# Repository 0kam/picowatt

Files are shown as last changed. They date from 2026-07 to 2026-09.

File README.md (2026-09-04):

# picowatt

Raspberry Pi Pico 2 + INA228 による PPK2 ライクな消費電力測定システム。

## クイックスタート

### リリース版を使う(推奨)

1. **ファームウェア**: [Releases](https://github.com/0kam/picowatt/releases) から
   `picowatt-vX.Y.Z.uf2` をダウンロードし、BOOTSEL ボタンを押しながら Pico 2 を
   USB 接続して現れる `RP2350` ドライブにドラッグ(または
   `picotool load -fx picowatt-vX.Y.Z.uf2`)。
2. **PC アプリ**: [uv](https://docs.astral.sh/uv/) があれば1行で起動できる:

   ```sh
   uvx picowatt        # GUI
   uvx --from picowatt picowatt-cli --seconds 10 --csv out.csv
   ```

   (pip 派は `pipx install picowatt` でも可)

### ソースからのビルドと書き込み

必要なもの: cmake、ARM GNU toolchain、[pico-sdk](https://github.com/raspberrypi/pico-sdk) 2.3+(`lib/tinyusb` サブモジュール込み)、picotool 2.3+。

```sh
export PICO_SDK_PATH=~/pico-sdk            # 既定値
export PICO_TOOLCHAIN_PATH=~/toolchains/arm-gnu-toolchain-...  # PATH に無い場合
./firmware/build.sh                        # → firmware/build/picowatt.uf2

# 初回のみ BOOTSEL ボタンを押しながら USB 接続して:
picotool load -fx firmware/build/picowatt.uf2
# 2回目以降はボタン不要(実行中ファームがリブートコマンドを受け付ける)
```

UF2 ドライブへのドラッグ&ドロップでも書き込めるが、USB マスストレージが
制限された環境では picotool 経由(PICOBOOT)が使える。

### PC アプリ

```sh
cd app
uv sync
uv run picowatt        # GUI
uv run picowatt-cli --seconds 10 --csv out.csv   # ヘッドレスキャプチャ
```

GUI: Connect → Start でストリーミング開始。Measure チェックで電力プロット上の
任意区間を選択して Wh/Ah を積算。Log CSV… で全サンプルをファイルに記録。
Calibrate… でゼロ校正・1点ゲイン校正(ボードIDごとに自動保存され、接続時に
自動適用)。プロトコル仕様は [docs/protocol.md](docs/protocol.md)、実測性能は
[docs/verification.md](docs/verification.md) を参照。値がおかしいときは
[docs/troubleshooting.md](docs/troubleshooting.md)（症状から引ける）。

## 概要

INA228 電力モニタを Pico 2 で読み取り、USB シリアル経由で PC に転送。PC 側アプリでリアルタイム表示・ロギング・任意区間の電力量(Wh)積算を行う。

対応する測定モード:

- **消費電力測定** — 機器の消費電力を INA228 1枚で測定
- **DC-DC 効率測定** — INA228 2枚で入出力を同時測定し、効率を算出

## ハードウェア構成

| 役割 | 型番 | 備考 |
|---|---|---|
| MCU | Raspberry Pi Pico 2 (RP2350) | USB CDC で PC 接続 |
| 電力モニタ | Adafruit INA228 ×2 | 15mΩ 0.1% シャント搭載、20bit ADC |
| ディスプレイ | SSD1306 128×64 I2C OLED | 秋月 |
| 電源 | アズワン PS30V5A10 | 0-30V / 0-5A |
| 電子負荷 | ET5410A+ | 効率測定時の負荷掃引用 |

### I2C アドレス

| デバイス | アドレス | 設定 |
|---|---|---|
| SSD1306 OLED | `0x3C` | — |
| INA228 #1 (入力側) | `0x40` | デフォルト |
| INA228 #2 (出力側) | `0x41` | 基板裏 A0 ジャンパを閉 |

### 結線

ロジック側は I2C0 バスに全デバイスをぶら下げる。ブレッドボード配線の代わりに
キャリア基板を起こす場合は [hardware/](hardware/README.md) を参照(KiCad プロジェクト)。

| Pico 2 | 接続先 |
|---|---|
| 3V3 OUT (pin 36) | INA228 ×2 VIN / OLED VCC |
| GND (pin 38) | INA228 ×2 GND / OLED GND / 電源 − (1点のみ) |
| GP4 (pin 6) SDA | INA228 ×2 SDA / OLED SDA |
| GP5 (pin 7) SCL | INA228 ×2 SCL / OLED SCL |

I2C プルアップは INA228 基板の 10kΩ が効くため追加不要。

ブレッドボードで組む場合の全体図（ロジック配線 + 電源経路）:

ブレッドボード配線: 消費電力測定

ブレッドボード配線: DC-DC 効率測定

電力ラインはハイサイド測定。**基板裏の VBus ジャンパを閉じる**(VBUS が VIN+ に接続され、ハイサイド構成になる)。

```
電源(+) → #1 VIN+ ─[15mΩ]─ #1 VIN− → DUT(+)
電源(−) ←──────────────────────────── DUT(−)
```

キャリア基板でのつなぎ方（赤 = ＋側、青 = −側。USB が左、端子台が上辺）:

消費電力測定のつなぎ方

効率測定時は出力側に #2 を追加:

```
DUT出力(+) → #2 VIN+ ─[15mΩ]─ #2 VIN− → 電子負荷(+)
DUT出力(−) ←───────────────────────────── 電子負荷(−)
```

DC-DC 効率測定のつなぎ方

ch1 用の INA228 は裏の A0 ジャンパを閉じて右の J3 に挿す。詳細は
[hardware/README.md](hardware/README.md#使い方配線図)。

**電源の − は必ず picowatt の GND（キャリア基板なら J5）に繋ぐ。** INA228 は
バス電圧を自分の GND ピン基準で測るので、この 1 本が無いと基板が電源系から
浮き、VBUS が 0 V と −数十 V の間を 50/60 Hz で振動する（実在しない電圧）。
GUI はステータスバー右端に赤字の警告を出し、`picowatt-cli` は
`WARNING: bus voltage goes negative` を出す。図解は [docs/troubleshooting.md](docs/troubleshooting.md)。

GND リンクを忘れるとこうなる

GND の共通接続は 1 点のみ。複数箇所で接続するとループになる。

## キャリブレーション

INA228 は `SHUNT_CAL` レジスタ (0x02) にシャント値とフルスケールから決まる係数を書き込む必要がある。

```
CURRENT_LSB = 最大期待電流 / 2^19
SHUNT_CAL   = 13107.2e6 × CURRENT_LSB × R_SHUNT
```

`R_SHUNT = 0.015` (Adafruit ボード搭載値)。

デフォルト設定 (3A 想定, ADCRANGE=0 / ±163.84mV):

```
CURRENT_LSB = 8e-6        # 8 µA/LSB, フルスケール約 4.19A
SHUNT_CAL   = 1573
```

低電流モード (ADCRANGE=1 / ±40.96mV) では CURRENT_LSB を 1/4 に下げて分解能を上げる。
ADCRANGE=1 では **SHUNT_CAL の計算値を 4 倍**する必要があるが、LSB の 1/4 と相殺して
レジスタ値は同じになる:

```
CURRENT_LSB = 2e-6        # 2 µA/LSB, フルスケール約 1.05A
SHUNT_CAL   = 1573        # = 4 × 13107.2e6 × 2e-6 × 0.015
```

出荷時のシャント実値は公称から数%ずれることがあるため、既知電流での 1 点校正を推奨。

## 機能要件

### ファームウェア (Pico 2)

- INA228 ×2 の初期化・設定変更 (ADCRANGE, 変換時間, 平均化回数)
- 定期サンプリングと USB シリアルへのストリーミング
- OLED へのリアルタイム数値表示
- PC からのコマンド受信 (レンジ切替、サンプリングレート変更、ゼロ校正、モード切替)
- I2C は 400kHz 以上 (Pico 2 は 1MHz まで可)

### PC アプリ

- シリアル接続とリアルタイムグラフ表示 (電圧 / 電流 / 電力)
- CSV ロギング
- **表示中の任意範囲を選択して電力量(Wh)を積算**
- 効率モード時は入出力電力と効率(%)を同時表示
- 測定設定の変更 UI

## 想定サンプリングレート

I2C 経由のため PPK2 (100kSa/s) 相当は狙わない。数百 Hz〜数 kHz を目標。変換時間と平均化回数の設定でノイズと速度をトレードオフする。

## 参考

- [Adafruit INA228 Learn Guide](https://learn.adafruit.com/adafruit-ina228-i2c-power-monitor)
- INA228 データシート (TI)

## ライセンス

GPL-3.0 — 詳細は [LICENSE](LICENSE) を参照。

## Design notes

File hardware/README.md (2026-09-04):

# picowatt キャリア基板

Pico 2 + INA228 ×2 + SSD1306 OLED を 1 枚に載せるキャリア基板。ロジックはすべて
I2C0 にぶら下がるだけなので、この基板は **電源と I2C を配るだけ** で能動素子を持たない。

- 基板サイズ **92 × 70 mm**（2 層、厚さ 1.6mm）。100×100mm 以内なので各社の最安枠に収まる
- 子基板（Pico 2 / INA228 ×2 / OLED）はすべて 2.54mm ソケットで着脱可能
- 高さはすべて **11.0mm の同一面** に揃う（ソケットのハウジング高さ 8.5mm +
  ピンヘッダのハウジング厚み 2.5mm、いずれも秋月の仕様値）

KiCad 10 で `picowatt-carrier.kicad_pro` を開く。シンボルとフットプリントのうち
本基板固有のものは `picowatt.kicad_sym` / `picowatt.pretty/` にプロジェクト内蔵。
残りは KiCad 標準ライブラリを参照する。

> KiCad を一度も起動していない環境ではグローバルライブラリテーブルが未作成のため、
> 標準ライブラリ参照がエラーになる。KiCad を一度起動すれば自動生成される。

## 配置の考え方

配線の向きを 3 方向に分離してある。

| 方向 | 出ていくもの |
|---|---|
| 上辺（奥） | INA228 ×2 のネジ端子台、GND 端子台 — 太い電源線はすべて奥へ |
| 左辺 | Pico 2 の Micro-USB B — PC へ |
| 手前 | OLED の表示面 |

INA228 の端子台が基板の外を向くので、電源線は基板の上を這わない。

J5 (GND 端子台) も同じ向きに揃えるため **180° 回転して配置してある。** TB007-508 の
機械図面 (SECTION A-A) では、ピン列は電線挿入面ではなく**背面から 4.90mm**（挿入面からは
5.35mm）の位置にある。回転 0 のままだと電線が手前から入り、基板の上をまたぐことになる。

## 回路

ネットは 6 本だけ。

| ネット | 接続先 |
|---|---|
| `+3V3` | Pico 2 pin36 (3V3 OUT) → INA228 ×2 の VIN、OLED VDD、プルアップ、パスコン |
| `GND` | Pico 2 の GND 群、各子基板 GND、GND 端子台、TP1 |
| `SDA` | Pico 2 GP4 (pin 6) → INA228 ×2、OLED |
| `SCL` | Pico 2 GP5 (pin 7) → INA228 ×2、OLED |
| `ALRT0` | Pico 2 GP6 (pin 9) → INA228 ch0 の ALRT |
| `ALRT1` | Pico 2 GP7 (pin 10) → INA228 ch1 の ALRT |

`ALRT0` / `ALRT1` は現ファームウェアでは未使用だが、`firmware/src/config.h` が
GP6/GP7 を予約済みで配線コストがゼロなので引いてある。INA228 側の ALRT は
オープンドレインなのに基板上にプルアップが無いため、R1/R2 (10kΩ) を本基板に載せる。

I2C プルアップは INA228 が各 10kΩ を持ち、2 枚並列で 5kΩ、さらに OLED モジュール分も
乗るので追加不要と判断した。R3/R4 は**未実装** (DNP) のパッドとして用意してあるだけで、
1MHz で波形が鈍る場合にのみ実装する。

### 電力ラインは基板に通さない

INA228 の 2.54mm ヘッダには `VBUS` / `VIN-` / `VIN+` も出ているが、**基板側は無接続**に
してある（J2/J3 の pin 5,6,7）。最大 5A の電力ラインをキャリア基板に通す理由がないため、
電源線は従来通り INA228 自身のネジ端子台に接続する。

> **注意**: 無接続とはいえ、このパッドには測定対象の電源電位（最大 30V）が乗る。
> シルクにも警告を入れてある。

## 部品表

Pico 2 / INA228 ×2 / OLED 以外はすべて秋月電子で揃う。**通販コードと寸法は商品ページで
実際に確認済み**（確認できなかった項目は末尾に明記）。

### 基板に実装するもの

| 通販コード | 品名 | 型番 | 単価 | 入数 | 必要 | Ref / 適合確認 |
|---|---|---|---|---|---|---|
| [103077](https://akizukidenshi.com/catalog/g/g103077/) | ピンソケット(メス) 1×20 | FH-1x20 | ¥50 | 1個 | 2 | J1。ピッチ2.54 / 高さ8.5mm |
| [103785](https://akizukidenshi.com/catalog/g/g103785/) | ピンソケット(メス) 1×8 | FH-1x8SG/RH | ¥30 | 1個 | 2 | J2,J3。高さ8.5mm |
| [110099](https://akizukidenshi.com/catalog/g/g110099/) | ピンソケット(メス) 1×4 | FH-1x4SG/RH | ¥20 | 1個 | 1 | J4。高さ8.5mm |
| [102333](https://akizukidenshi.com/catalog/g/g102333/) | ターミナルブロック 2P 緑 縦 小 | — | ¥35 | 1個 | 1 | J5。**5.08mmピッチ・水平引出し・ねじ式** |
| [125103](https://akizukidenshi.com/catalog/g/g125103/) | カーボン抵抗 1/4W 10kΩ | RD25S | ¥100 | 1袋100本 | 1袋 | R1,R2。立て実装 |
| [125222](https://akizukidenshi.com/catalog/g/g125222/) | カーボン抵抗 1/4W 2.2kΩ | CF25J2K2B | ¥150 | 1袋100本 | 1袋 | R3,R4。**未実装なので省略可** |
| [117897](https://akizukidenshi.com/catalog/g/g117897/) | 電解コンデンサー 10µF50V ルビコンPX | 50PX10MEFC5X11 | ¥10 | 1個 | 1 | C1。φ5×11mm / **端子間2mm** |
| [110147](https://akizukidenshi.com/catalog/g/g110147/) | 積層セラミックコンデンサー 0.1µF250V X7R | RDER72E104K2K1H03B | ¥25 | 1個 | 1 | C2。**端子間5mm** / 5.5×3.15×4mm |
| [112217](https://akizukidenshi.com/catalog/g/g112217/) | チェック端子 TEST-34 | TEST-34 | ¥15 | 1個 | 1 | TP1。径0.8mm |

小計 **約 ¥585**（2.2kΩ を省けば約 ¥435）。

> C2 を安く済ませたい場合は [112670](https://akizukidenshi.com/catalog/g/g112670/)
> (0.1µF 50V X7R **2.54mm**ピッチ, ¥10) でもよい。基板のパッドは 5mm ピッチなので
> リードを外側へ広げて挿す。小型 MLCC なので実際には問題にならない。

### 子基板側に付けるピンヘッダ

| 通販コード | 品名 | 型番 | 単価 | 必要 | 備考 |
|---|---|---|---|---|---|
| [100167](https://akizukidenshi.com/catalog/g/g100167/) | ピンヘッダー 1×40 | PH-1x40SG | ¥35 | 2 | 切って使う。ハウジング厚み2.5mm |

Pico 2 用に 1×20 ×2、INA228 用に 1×8 ×2 で計 56 ピン。1×40 を 2 本で足りる。
**Pico 2 H（ヘッダ実装済み）を使うなら 1 本でよい。** OLED は多くの場合ヘッダ付属。

### 機構部品

**キャリア側の穴はタップの無い通し穴**（子基板用 φ2.8、四隅 φ3.2）。メス-メスの
スタンドオフを子基板とキャリアで挟み、上下からネジで留める。

**必要な高さは 11.0mm。** ソケットのハウジング高さ 8.5mm + ピンヘッダのハウジング厚み
2.5mm で、どちらも秋月の仕様値。子基板の裏面はキャリア面から 11.0mm に来る。

| 用途 | 通販コード | 品名 | 単価 | 必要 |
|---|---|---|---|---|
| 四隅の脚 | [107313](https://akizukidenshi.com/catalog/g/g107313/) | 六角両メネジ FB3-10 (黄銅 M3 10mm) | ¥30 | 4 |
| 同ネジ | [110329](https://akizukidenshi.com/catalog/g/g110329/) | なべ小ねじ(+) M3×10 | ¥180/10個 | 1袋 |

**M2.5 のスペーサーは秋月では扱っていない**（複数のキーワードで検索して確認）。
子基板用は次のどちらかになる。

- **秋月だけで揃える場合**: [113017](https://akizukidenshi.com/catalog/g/g113017/)
  プラスチックスペーサー M2×10mm ¥20 ×8 +
  [113020](https://akizukidenshi.com/catalog/g/g113020/) なべ小ねじ プラスチック M2×5mm
  ¥10 ×16。M2 は φ2.8 の穴に対して緩いが、スペーサーが厚みを決めるので実用上は問題ない。
  10mm なので 1mm 足りず、ワッシャで詰めるか軽く締める程度にする
- **寸法どおりに揃える場合**: M2.5 メス-メス 11mm を廣杉計器などから調達する

なお子基板は 8pin / 4pin のソケット自体でも保持されるので、**スタンドオフは剛性を上げる
ためのもので必須ではない。** ただし INA228 は端子台をドライバーで締めるため、付けた方がよい。

### 確認していないこと

- `102333` の電線挿入口がフットプリントのどちら向きかは未確認。**J5 は両ピンとも GND なので
  向きは電気的に無関係**で、線を出したい方向に合わせて挿せばよい
- ソケットの推奨実装穴径は 1.02mm、基板の穴は 1.0mm。0.02mm の差はドリル公差の範囲内で、
  一般的な 2.54mm ソケットの実装として標準的な値
- 秋月の在庫状況・価格は 2026-07 時点の商品ページの表示

## 組み立て時の設定

シルクにも印刷してあるが、忘れやすいので再掲。

1. **ソケットとチャンネルの対応**: 左の J2 = ch0 (0x40, 入力側)、右の J3 = ch1
   (0x41, 出力側)。各ソケットの左脇に `ch0 0x40 IN` / `ch1 0x41 OUT` を縦書きで
   印刷してある
2. **ch1 に挿す INA228 は裏の A0 ジャンパを閉じる** → アドレス 0x41
   （ch0 用は開放のまま 0x40）
3. **INA228 ×2 とも裏の VBus ジャンパを閉じる** → ハイサイド測定になる
4. **GND の共通接続は 1 点のみ。** 安定化電源の − は J5 だけに落とす

## 使い方（配線図）

図は実物と同じ向き（USB が左、端子台が上辺）。**赤 = ＋側、青 = −側**。
いずれのモードでも測定電流は INA228 モジュール自身のネジ端子台を通り、
**キャリア基板の信号配線には流れない**（J2/J3 の pin 5-7 は無接続）。

- **J5 の 2 つの口はどちらも GND** で、基板内の両面ベタで繋がっている。
  消費電力測定では DUT の−と電源の−を**別々の口に**挿せばよく、
  線を途中で分岐させる必要はない（2 口間の戻り電流は幅の広いベタを
  約 5mm 通るだけで、サブ mΩ・実害なし）
- 効率測定では電源の−端子に 2 本を共締めする
  （DCDC の IN− を J5 の空き口に挿す形でも同じ）
- **端子台の真ん中のネジ (VBus) には何も繋がない**

### 消費電力測定（INA228 1 枚、ch0 のみ）

INA228 は A0 開放のまま **J2**（左、シルク `ch0 0x40 IN`）に挿す。

消費電力測定のつなぎ方

### DC-DC 効率測定（INA228 2 枚、ch0 + ch1）

ch1 用の INA228 は裏の A0 を閉じて **J3**（右、シルク `ch1 0x41 OUT`）に挿す。

DC-DC 効率測定のつなぎ方

この結線は **非絶縁 DC-DC**（IN− と OUT− が内部で共通）を前提にしている。
絶縁型を測る場合は ch1 のバス電圧の基準が浮いてしまうので、OUT− 側も
基準電位へ 1 点で接続すること。

### よくある間違い：電源の − を J5 に繋ぎ忘れる

INA228 は VBUS を **自分の GND ピン基準**で測る。GND ピンは基板の GND ベタに
落ちているだけなので、電源の − が J5 に来ていないと基板全体が電源系から浮き、
VBUS が 0 V と −数十 V の間を 50/60 Hz で振動する。電流はそれらしく出るので
気付きにくい。

GND リンクを忘れた配線

VBUS は INA228 の GND ピン基準

電源の − から J5 の空き口へ 1 本足せば直る。`picowatt-cli` はこの状態を
`WARNING: bus voltage goes negative` として報告する。他の症状は
[docs/troubleshooting.md](../docs/troubleshooting.md)。

図は `tools/wiring_diagrams.py` が基板と同じ座標データから生成している。

## 配線

2 層、配線 57 本 + ビア 8 個。**未配線 0 件・ERC 0 件**で検証済み
（DRC は後述の回転由来の警告 1 件のみ、実害なし）。

| 層 | 用途 |
|---|---|
| B.Cu | `+3V3` 幹線（Y=42.2mm を横断）+ ベタ GND |
| F.Cu | 信号 4 本 + ベタ GND |

`GND` は両面ベタで配るため配線を持たない。全 GND パッドの導通は、ゾーンを塗った状態で
`pcbnew` の接続性チェックにより確認済み（ベタは分断されていない）。

配線幅は信号 0.3mm、電源 0.4mm。全パッドがスルーホールなので、層をまたぐのは
交差回避の 4 箇所（ビア 8 個）だけ。

### 帯状のレーン構成

バンド（Y 33〜38mm）に 4 本の信号レーンを平行に走らせ、そこから各コネクタへ分岐する。

| ネット | レーン Y | Pico 上側列を抜ける X |
|---|---|---|
| `SDA` | 37.2mm | 13.80mm |
| `SCL` | 36.0mm | 16.34mm |
| `ALRT0` | 34.8mm | 23.96mm |
| `ALRT1` | 33.6mm | 26.50mm |

**Pico 2 の下側列（GP4/5/6/7）から上へ抜けるとき、上側列のパッドの隙間を通している。**
パッド径 1.6mm・ピッチ 2.54mm なのでパッド中心から 1.27mm、銅箔間で 0.32mm 空く。
本基板で最も攻めた箇所だが、各社の下限（0.127mm 程度）に対しては十分な余裕がある。

レーンの上下順は「Pico から抜ける X が左のものほど上のレーン」に揃えてあり、
これにより 4 本の立ち上がりが互いに交差しない。上のレーンを跨がざるを得ない
以下の 4 箇所だけ、B.Cu へ潜って戻している（ビア 2 個 × 4 = 8 個）。

| ネット | X | 跨ぐレーン |
|---|---|---|
| `SCL` | 18.19 | `SDA` |
| `SCL` | 48.19 | `SDA` |
| `ALRT0` | 30.89 | `SCL` と `SDA` |
| `ALRT1` | 60.89 | `SCL` と `SDA` |

### プルアップ抵抗の置き方

R1〜R4 は**配線の通り道の上に直接置いてある**。信号側のパッドは 4 本とも既存の配線上に
乗るので、信号側の引き込み配線は 1 本もない。+3V3 側は裏面に 2.8〜4.2mm のスタブが
3 本あるだけで、R4 は +3V3 の既存配線上に乗るためスタブすら不要。

| Ref | 役割 | 信号側パッドが乗っている配線 |
|---|---|---|
| R1 | `ALRT0` プルアップ | ALRT0 の J2.8 への立ち上がり (X=30.89) |
| R2 | `ALRT1` プルアップ | ALRT1 の J3.8 への立ち上がり (X=60.89) |
| R3 | `SDA` プルアップ (未実装) | SDA の OLED への下り (X=74.81) |
| R4 | `SCL` プルアップ (未実装) | SCL の OLED への下り (X=72.27) |

いずれも配線の途中から分岐する形（直列ではない）なので、**R3/R4 を未実装のままでも
`SDA` / `SCL` は繋がる。**

> 当初は 10.16mm ピッチの抵抗を基板左側に並べていたが、配線してみると信号側パッドが
> 基板左端に来てしまい、先に引いた `SDA` の縦線を必ず跨ぐため層をまたぐ箇所が 5 つ必要になった。
> 2.54mm ピッチの立て実装に変更し、配線経路上へ移動して解消している。

## tools/

この基板は生成スクリプトで作られている。**KiCad ファイルが正であり、これらを再実行すると
上書きされる**ので、レイアウトを作り直すとき以外は触らなくてよい。

| ファイル | 役割 |
|---|---|
| `generate.py` | 部品配置・ネットリスト・ベタ・シルクを含む KiCad プロジェクトを生成 |
| `routes.py` | 配線をキャリア座標のポリラインで定義 |
| `routelib.py` | 基板の読み取り、クリアランス／接続性の事前チェック、配線の書き出し |
| `audit.py` | 保存済み基板から配線を読み直し、実クリアランス余裕を報告 |
| `wiring_diagrams.py` | README 用の配線図 (docs/wiring-*.svg, docs/breadboard-*.svg, docs/vbus-reference.svg) を生成 |

再生成する場合は `generate.py` → `routelib.emit()` → `pcbnew` でゾーン塗り、の順。
`audit.py` は KiCad の DRC とは独立に幾何を検算するので、変更後の確認に使える。

## 発注

2 層・1.6mm・92×70mm。特殊な要求は無いので JLCPCB / PCBWay / Elecrow のいずれでも最安枠。

```sh
kicad-cli pcb export gerbers picowatt-carrier.kicad_pcb -o gerber/
kicad-cli pcb export drill   picowatt-carrier.kicad_pcb -o gerber/
```

## 既知のリスク

**OLED モジュールのロット差。** 秋月 112031 は商品ページに「ロットにより外観が異なります」
と明記されており、秋月が配布している参考 PDF は実物と別基板（PDF は 27.3×27.3mm /
シルク `GND VCC SCL SDA`、実物は 25×27mm / `GND VDD SCK SDA`）。本設計は**実測値**
（外形 25×27mm、取付穴ピッチ 21×23mm、穴径 φ2.75、ヘッダは上辺から 1.5mm）に基づく。

交換品を買う場合は寸法だけでなく **ピンの並び順も必ず確認すること。** この種のモジュールには
`GND` と `VCC` が逆のロットが実在する。取付穴が左右対称 (±10.5mm) なので**逆順品でも機械的には
刺さってしまい、電源を逆接する**。基板は pin1=GND / pin2=VDD 前提。

この事故を防ぐため、**基板のシルクに各パッドのピン名を印刷してある。**

- J4 の 4 パッドの脇に `GND` `VDD` `SCK` `SDA` を縦書きで(モジュールを載せる前、
  はんだ付けの段階で手元のモジュールと突き合わせられる)
- 基板下端に `J4 OLED pin1=GND VDD SCK SDA` を 1 行(モジュール実装後も読める)
- J2/J3 も同様に `VIN GND SCL SDA VBUS VIN- VIN+ ALRT` を各パッド脇に印刷

**回転したフットプリントの `lib_footprint_mismatch` 警告。** J5 は 180° 回転して配置して
あるため、`kicad-cli pcb drc` がこの警告を 1 件出す。回転させたフットプリントであれば
部品を問わず出る kicad-cli 側の比較の癖で（無関係な部品を回して再現確認済み）、
実体は隠しテキストの角度差。製造・機能への影響はない。

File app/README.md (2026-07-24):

# picowatt PC application

Realtime viewer / logger for the picowatt measurement device.

## Setup

```sh
cd app
uv sync
```

## Usage

```sh
uv run picowatt          # GUI
uv run picowatt-cli      # headless capture (from M4)
```

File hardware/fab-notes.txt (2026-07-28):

Fabrication notes -- picowatt carrier board
===========================================

Board outline : 92.0 x 70.0 mm, plain rectangle, no cutouts, slots or
                V-scoring. Outline is on the Edge_Cuts layer.
Layers        : 2 (FR-4, 1.6 mm, 1 oz finished copper)
Min track     : 0.30 mm (11.8 mil)
Min spacing   : 0.20 mm (7.9 mil)
Min drill     : 0.40 mm (vias)
Min annular   : 0.20 mm (vias), 0.30 mm (component pads)

IMPORTANT -- the 12 mounting holes must be NON-PLATED (NPTH)
------------------------------------------------------------
They are supplied in a separate drill file, picowatt-carrier-NPTH.drl:

    8 x 2.8 mm   standoffs under the daughterboards
    4 x 3.2 mm   board mounting feet

Plating these would connect the mounting screws to the board ground.

All remaining holes are plated (picowatt-carrier-PTH.drl), 83 in total:

    8 x 0.4 mm   vias
   12 x 0.8 mm   resistors and capacitors
   61 x 1.0 mm   pin sockets and test point
    2 x 1.6 mm   screw terminal

Other
-----
No SMD parts on this board, so no solder paste stencil is required.
Surface finish: HASL is fine, all assembly is through-hole hand soldering.

Files
-----
Gerber RS-274X : *.gtl .gbl .gto .gbo .gts .gbs .gm1
Drill (Excellon, mm, absolute origin) : *-PTH.drl, *-NPTH.drl
Drill maps     : *-drl_map.gbr
Job file       : *-job.gbrjob

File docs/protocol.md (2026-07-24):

# picowatt serial protocol v1

Binary protocol over USB CDC. This document is the single source of truth;
`firmware/src/proto.*` and `app/src/picowatt/protocol.py` implement it.

## Framing

Every frame is COBS-encoded and terminated with a single `0x00` byte.
COBS guarantees no `0x00` inside the encoded frame, so a receiver can always
resynchronize at the next zero byte.

Unencoded frame layout (before COBS):

```
type:u8 | payload:u8[] | crc16:u16le
```

- `crc16` = CRC-16/CCITT-FALSE (poly 0x1021, init 0xFFFF, no reflection,
  no final xor) computed over `type + payload`.
- All multi-byte integers are **little-endian**.
- Maximum unencoded frame size: 300 bytes.

## Frame types

### FW → PC

| Type | Name | Payload |
|---|---|---|
| 0x01 | DATA | `frame_seq:u16` `count:u8` then `count` × record (13 B, below) |
| 0x80 | ACK | `cmd:u8` (the command type being acknowledged) |
| 0x81 | NACK | `cmd:u8` `err:u8` (1=bad param, 2=channel absent, 3=unknown cmd, 4=bad length) |
| 0x90 | HELLO_ACK | `proto_ver:u8` `fw_major:u8` `fw_minor:u8` `fw_patch:u8` `board_id:u8[8]` `ch_present:u8` (bitmask: bit0=ch0, bit1=ch1) |
| 0x96 | CONFIG | `mode:u8` `streaming:u8` `drops:u32` then 2 × per-channel block (7 B, below) |

DATA record (13 bytes):

```
ch:u8        0 = input side (0x40), 1 = output side (0x41)
t_us:u32     device microsecond timer at CNVRF detection; wraps every ~71.6 min
vbus_raw:i32 VBUS register, 20-bit sign-extended counts. LSB = 195.3125 µV
curr_raw:i32 CURRENT register, 20-bit sign-extended counts.
             LSB = 8 µA (ADCRANGE=0) or 2 µA (ADCRANGE=1)
```

`frame_seq` increments by 1 per DATA frame (wraps at 65535). A gap means
dropped frames. Records within a frame are in acquisition order but may
interleave channels.

CONFIG per-channel block (7 bytes):

```
present:u8  adcrange:u8  vbusct:u8  vshct:u8  avg:u8  shunt_cal:u16
```

`vbusct`/`vshct`/`avg` are raw INA228 field codes (datasheet tables 7-x):
CT: 0=50µs 1=84µs 2=150µs 3=280µs 4=540µs 5=1052µs 6=2074µs 7=4120µs;
AVG: 0=1 1=4 2=16 3=64 4=128 5=256 6=512 7=1024.

### PC → FW

| Type | Name | Payload | Response |
|---|---|---|---|
| 0x10 | HELLO | `proto_ver:u8` | HELLO_ACK (NACK if version mismatch) |
| 0x11 | START | — | ACK; DATA frames begin |
| 0x12 | STOP | — | ACK; DATA frames cease |
| 0x13 | SET_MODE | `mode:u8` (0=single, 1=dual) | ACK / NACK(2) if ch1 absent |
| 0x14 | SET_ADC | `ch:u8` (0/1/0xFF=both) `adcrange:u8` `vbusct:u8` `vshct:u8` `avg:u8` | ACK |
| 0x15 | SET_SHUNT_CAL | `ch:u8` `val:u16` | ACK |
| 0x16 | GET_CONFIG | — | CONFIG |
| 0x1F | REBOOT_BOOTSEL | — | (no response; device reboots into BOOTSEL for flashing) |

Setting `bit_rate` to 1200 baud on the CDC line coding also reboots into
BOOTSEL (Arduino-style touch reset).

## Session flow

```
PC opens port
PC → HELLO(proto_ver=1)         ← must ACK within 500 ms with matching version
PC → GET_CONFIG                 ← learn mode / ranges / shunt_cal
PC → SET_SHUNT_CAL, SET_ADC ... ← push stored calibration & settings
PC → START                      ← DATA frames stream until STOP
```

The device is stateless across power cycles (no flash writes); the PC re-pushes
configuration on every connect. `GET_CONFIG` is the source of truth for
converting `curr_raw` (CURRENT_LSB depends on ADCRANGE).

## Rate presets (PC-side convenience, both channels)

| Preset | CT code | AVG code | Rate/ch approx. |
|---|---|---|---|
| fast (single only) | 2 (150 µs) | 0 | ~3.3 kHz |
| fast-dual (default) | 3 (280 µs) | 0 | ~1.8 kHz |
| normal | 4 (540 µs) | 0 | ~925 Hz |
| quiet | 5 (1052 µs) | 1 (4×) | ~119 Hz |
| very-quiet | 7 (4120 µs) | 2 (16×) | ~7.6 Hz |

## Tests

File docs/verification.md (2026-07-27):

# Hardware verification log

Bench: PS30V5A10 supply, ET5410A+ electronic load, Adafruit INA228 ×2
(15 mΩ), Pico 2, macOS host. 2026-07-24.

## M2 — single-channel accuracy (uncalibrated)

5.00 V supply, 0.500 A CC load:

| Quantity | Reading | Note |
|---|---|---|
| VBUS | 4.9457 V (sd 1.4 mV) | −54 mV vs supply setpoint = lead drop at 0.5 A |
| Current | 0.49981 A (sd 1.6 mA) | −0.04 % vs load setpoint |

Settings: ADCRANGE=0, 540 µs CT, AVG=16.

## M4 — streaming rates (1 MHz I2C)

| Preset | Theory | Measured | Gaps / drops |
|---|---|---|---|
| fast (single) | 3333 Hz | 3193 Hz (−4.2 %) | 0 / 0 |
| fast-dual (dual) | 1786 Hz/ch | 1714 Hz/ch | 0 / 0 |
| normal | 926 Hz | 907 Hz | 0 / 0 |

10-minute soak at fast: 1,916,273 samples, 0 frame gaps, 0 ring drops.
Δt: median 1093 µs vs 1080 µs theoretical; p99 1.8 ms; max 3.1 ms
(OLED page-write interleave; device timestamps make this harmless).

## M6 — energy integration

GUI region (19.627 s): 13.4911 mWh → P_avg 2.4747 W.
Offline CSV re-integration (separate 9.9 s log, same load): P_avg 2.4738 W.
Agreement 0.04 %.

## M7 — dual-channel efficiency

Null test (both shunts in series, same current): **η = 99.84 %**
(uncalibrated; criterion 100 ± 2 %).

DC-DC test: 秋月 M78AR05-1 (5 V / 1 A), 12 V input, load sweep:

| I_out | η (GUI) |
|---|---|
| 0.01 A | 51.81 % |
| 0.05 A | 81.95 % |
| 0.10 A | 87.42 % |
| 0.20 A | 91.45 % |
| 0.30 A | 91.78 % |
| 0.40 A | 91.71 % |

Plateau agrees with the datasheet typical (~92 % at 12 V in) within ~1 %;
light-load rolloff consistent with quiescent-current loss.

## M8 — calibration (2026-07-27)

ch0, ADCRANGE=0. Zero cal at no load, one-point gain cal at ET5410A+
CC ~1.0 A → **SHUNT_CAL 1573 → 1571** (−0.13 %, shunt near nominal).

| Load setpoint (ET5410A+ readout) | picowatt reading | Deviation |
|---|---|---|
| 0.101 A | 0.10215 A | +1.1 mA (within the load meter's ±(0.05%+0.05%FS) uncertainty) |
| 1.995 A | 1.9958 A | **+0.04 %** |

Disconnect → reconnect restores calibration automatically (profile keyed by
board_id) and streaming stays stable (after the stale-backlog and
buffer-reset fixes).

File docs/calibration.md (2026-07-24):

# Calibration

## SHUNT_CAL register

The INA228 computes CURRENT from VSHUNT using the SHUNT_CAL register (0x02):

```
CURRENT_LSB = full-scale current / 2^19
SHUNT_CAL   = 13107.2e6 × CURRENT_LSB × R_SHUNT      (ADCRANGE = 0)
SHUNT_CAL   = 4 × 13107.2e6 × CURRENT_LSB × R_SHUNT  (ADCRANGE = 1)
```

`R_SHUNT = 0.015 Ω` (Adafruit INA228 board, 0.1%).

### picowatt operating points

| Mode | ADCRANGE | Shunt range | CURRENT_LSB | Full scale | SHUNT_CAL |
|---|---|---|---|---|---|
| Default | 0 | ±163.84 mV | 8 µA | ≈4.19 A | 1573 |
| Low current | 1 | ±40.96 mV | 2 µA | ≈1.05 A | 1573 |

The register value is identical in both modes: the ×4 factor for ADCRANGE=1
cancels against the 4× smaller CURRENT_LSB. **The PC must always convert
`curr_raw` with the CURRENT_LSB matching the range the device actually has** —
GET_CONFIG is the source of truth.

Other fixed LSBs (range-independent unless noted):

| Quantity | LSB |
|---|---|
| VBUS | 195.3125 µV |
| VSHUNT | 312.5 nV (range 0) / 78.125 nV (range 1) |

## Zero-offset calibration (PC-side)

With no load connected, residual current readings (ADC offset, board leakage)
are averaged over ~1 s and stored per `board_id` in the PC profile. The offset
(in raw counts) is subtracted from every sample on the PC. No firmware state.

## One-point gain calibration

Shunt resistors are within a few % of nominal; a one-point calibration against
a known current removes most of the error:

1. Drive a known current `I_ref` through the channel (e.g. ET5410A+ in CC mode
   at 1.000 A, cross-checked on its readout).
2. Read the measured current `I_meas` (zero-offset already applied).
3. `SHUNT_CAL_new = round(SHUNT_CAL_current × I_ref / I_meas)`
4. Write it via SET_SHUNT_CAL and store it in the PC profile for this board_id.

Gain correction lives in the device register (so the OLED also shows calibrated
values); it is re-pushed by the PC on every connect.

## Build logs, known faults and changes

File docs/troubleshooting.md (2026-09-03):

# トラブルシューティング

症状から原因へ引けるように並べてある。配線図は
[hardware/README.md](../hardware/README.md#使い方配線図) を参照。

## 症状早見表

| 症状 | まず疑うこと |
|---|---|
| VBUS が 0 V と −数十 V の間を 50/60 Hz で振動する | **電源の − が J5 (GND) に来ていない** |
| VBUS が 0 V 付近で動かない、電流は出ている | INA228 裏の **VBus ジャンパが開いている** |
| 電流の符号が逆（負の電流） | VIN+ と VIN− が逆 |
| ch1 が `channels 0x01` で見えない | ch1 の A0 ジャンパが開いている（0x40 が 2 枚） |
| `frame gaps` / `ring drops` が 0 でない | USB 帯域超過。プリセットを落とす |

## VBUS が 0 V と −数十 V の間で振動する（GND リンク忘れ）

**症状**: 電源を入れても VBUS が安定せず、0 V と −50 V 前後の間を商用電源の
周波数（東日本 50 Hz / 西日本 60 Hz）で往復する。電流値はそれらしく見える
ことが多い。GUI はステータスバー右端に赤字で
`⚠ ch0: bus voltage goes negative (min -53.1 V) — check GND link to J5 / VBus jumper`
を出し続け、`picowatt-cli` は次を出す。

```
       vbus -26.1234 V (sd 18.7, min -53.1, max 0.2)  current 120.0 mA (sd 0.4)
       WARNING: ch0 bus voltage goes negative (min -53.1 V) - the supply '-' is
       probably not connected to the GND terminal (J5), or the VBus jumper is
       open. See docs/troubleshooting.md
```

**原因**: INA228 の A/D は VBUS を **自分の GND ピン基準**で測る。GND ピンは
キャリア基板の GND ベタ（＝Pico の GND）に繋がっているだけで、測定対象の
電源系とは **J5 を通してしか繋がらない**。電源の − を J5 に落とし忘れると
基板全体が電源系から浮き、浮いた導体が商用電源のハムを拾って、実在しない
電圧が表示される。

VBUS は INA228 の GND ピン基準

よくある形は「電源の − を測定対象の − に直結して、J5 には何も繋がない」。
線としては閉じているので気付きにくい。

GND リンクを忘れた配線

**対処**: 安定化電源の − から J5 の空いている口へ線を 1 本足す。これだけで
直る。この線には測定電流はほぼ流れない（電位を決めるだけ）ので細くてよい。

**注意**: GND の共通接続は **1 点だけ**にする。電源の − と測定対象の − の
両方を J5 に落とすのは正しい（J5 の 2 口は基板内で繋がっており、それが
1 点）。それとは別に PC の USB GND などを経由して 2 か所目ができるとループに
なる。

## VBUS が 0 V のまま動かない（VBus ジャンパ開放）

**症状**: 電流は正しく出るが VBUS だけ 0 V 付近で動かない、または微小な
ハムだけ乗る。

**原因**: Adafruit INA228 の VBUS ピンはデフォルトで VIN+ から切り離されて
いる。裏面の **VBus ジャンパ**を閉じないとバス電圧を測る配線が無い。

**対処**: INA228 ×2 とも裏の VBus ジャンパをはんだで閉じる（ハイサイド構成）。

## 電流が負になる

VIN+ と VIN− が逆。電源（または DC-DC 出力）の ＋ を **VIN+** に、負荷側を
**VIN−** に繋ぐ。ネジ端子台の真ん中（VBus）には何も繋がない。

## ch1 が見えない

接続時のログが `channels 0x01` なら ch1 が応答していない。ch1 に挿した
INA228 の裏の **A0 ジャンパ**が閉じているか確認する（閉で 0x41）。開いた
ままだと 0x40 が 2 枚になり、ch1 は存在しない扱いになる。

## frame gaps / ring drops が出る

`picowatt-cli` の末尾に出る `frame gaps` はホスト側の取りこぼし、`device
ring drops` は Pico 側のリングバッファ溢れ。どちらも 0 が正常。出る場合は
`--preset` を遅いものにするか、USB ハブを介さず直結する。プリセット一覧は
[protocol.md](protocol.md)。

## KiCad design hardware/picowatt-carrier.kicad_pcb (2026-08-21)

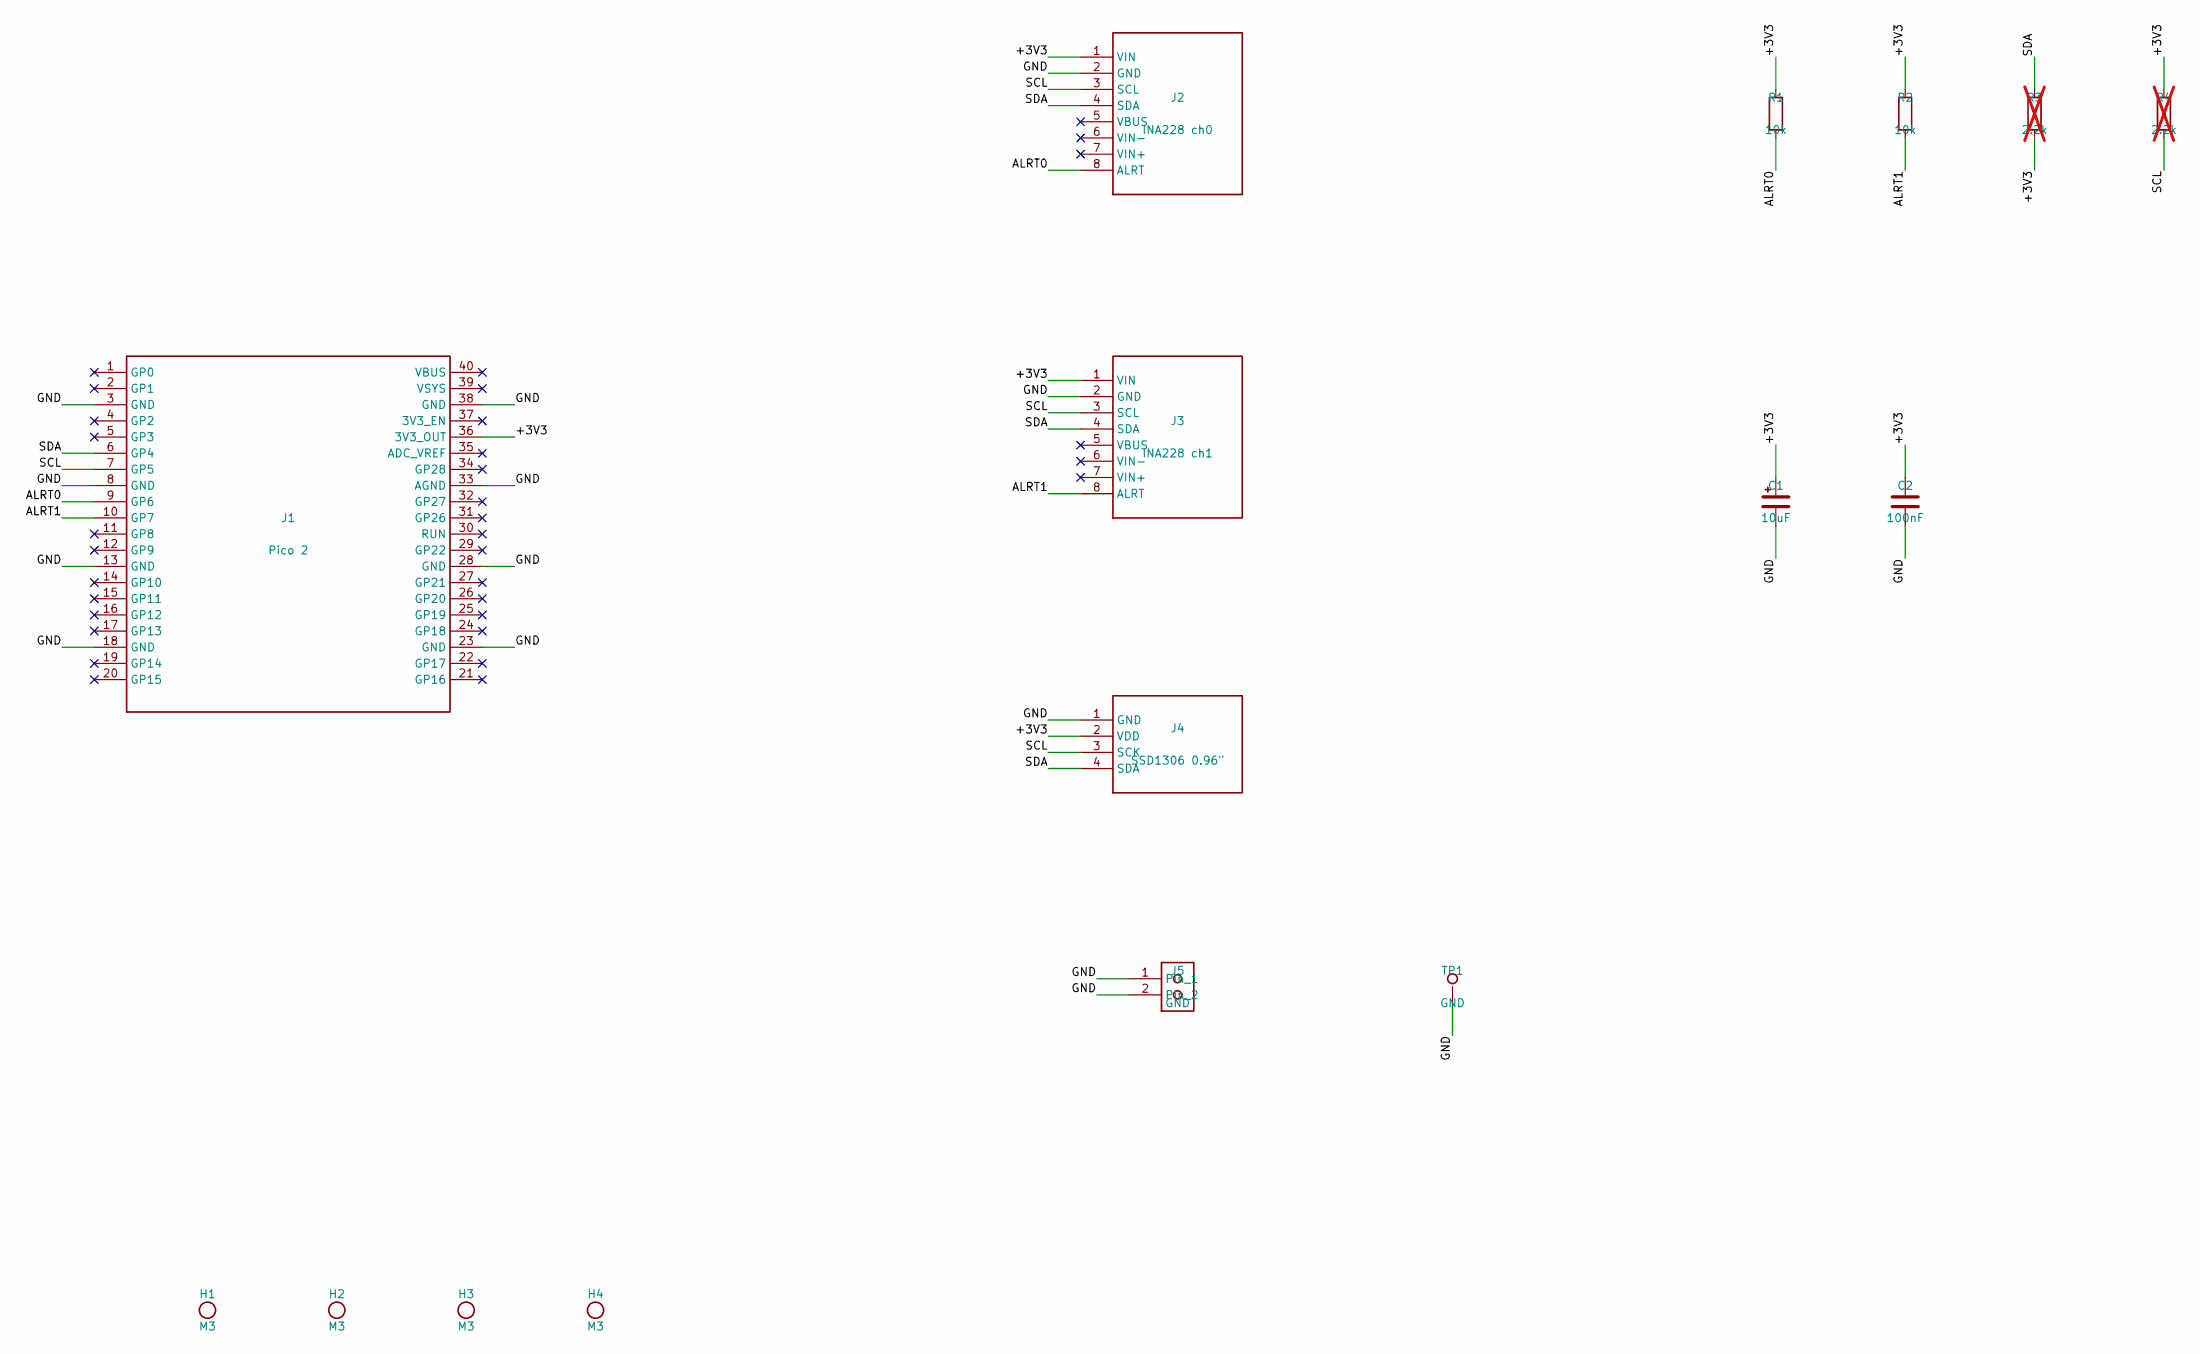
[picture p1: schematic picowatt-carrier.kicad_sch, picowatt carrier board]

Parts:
C1: 10uF; CP_Radial_D5.0mm_P2.00mm
C2: 100nF; C_Disc_D5.0mm_W2.5mm_P5.00mm
H1, H2, H3, H4: M3; MountingHole_3.2mm_M3
J1: Pico 2; Pico2_Socket_2x20_P2.54mm
J2: INA228 ch0; INA228_Breakout_Socket_1x08
J3: INA228 ch1; INA228_Breakout_Socket_1x08
J4: SSD1306 0.96"; OLED_SSD1306_Socket_1x04
J5: GND; TerminalBlock_CUI_TB007-508-02_1x02_P5.08mm_Horizontal
R1, R2: 10k; R_Axial_DIN0207_L6.3mm_D2.5mm_P2.54mm_Vertical
R3, R4: 2.2k; R_Axial_DIN0207_L6.3mm_D2.5mm_P2.54mm_Vertical; not fitted
TP1: GND; TestPoint_Loop_D2.50mm_Drill1.0mm

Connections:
/+3V3: C1.1, C2.1, J1.36 (3V3_OUT), J2.1 (VIN), J3.1 (VIN), J4.2 (VDD), R1.1, R2.1, R3.2, R4.1
/ALRT0: J1.9 (GP6), J2.8 (ALRT), R1.2
/ALRT1: J1.10 (GP7), J3.8 (ALRT), R2.2
/GND: C1.2, C2.2, J1.3 (GND), J1.8 (GND), J1.13 (GND), J1.18 (GND), J1.23 (GND), J1.28 (GND), J1.33 (AGND), J1.38 (GND), J2.2 (GND), J3.2 (GND), J4.1 (GND), J5.1, J5.2, TP1.1
/SCL: J1.7 (GP5), J2.3 (SCL), J3.3 (SCL), J4.3 (SCK), R4.2
/SDA: J1.6 (GP4), J2.4 (SDA), J3.4 (SDA), J4.4 (SDA), R3.1

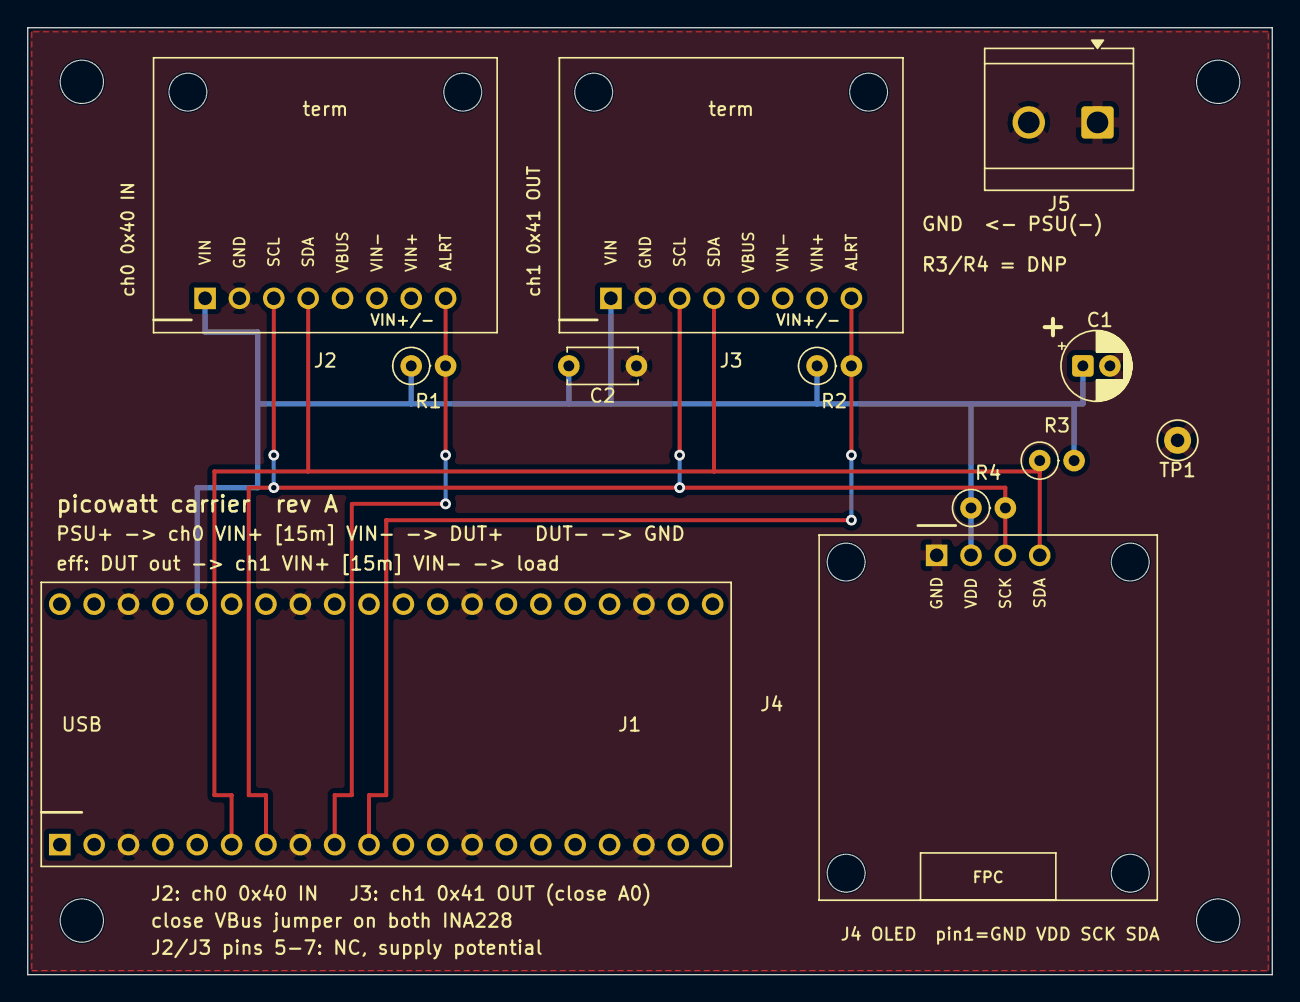
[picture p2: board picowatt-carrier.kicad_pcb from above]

Board: 2 copper layers, 92.0 x 70.0 mm, 16 parts (0 on the bottom side), 6 nets.

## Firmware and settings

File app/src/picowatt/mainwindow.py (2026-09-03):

"""picowatt GUI: realtime V/I/P plots with device control."""

from __future__ import annotations

import sys

import numpy as np
from PySide6.QtCore import Qt, QTimer
from PySide6.QtWidgets import (
    QApplication,
    QCheckBox,
    QComboBox,
    QDockWidget,
    QDoubleSpinBox,
    QFileDialog,
    QLabel,
    QMainWindow,
    QMessageBox,
    QPushButton,
    QToolBar,
)

from . import protocol as proto
from .buffer import ChannelBuffer
from .calibration import CalibrationStore
from .csv_logger import CsvLogger
from .device import find_ports
from .dialogs import AdvancedSettingsDialog, CalibrationDialog
from .measure import check_vbus, integrate_region
from .plots import CH_NAMES, LivePlots
from .serial_link import SerialWorker

BUFFER_CAPACITY = 9_000_000  # ~45 min at 3.3 kHz, ~144 MB


class MainWindow(QMainWindow):
    def __init__(self) -> None:
        super().__init__()
        self.setWindowTitle("picowatt")
        self.resize(1100, 750)

        self.worker: SerialWorker | None = None
        self.buffers = [ChannelBuffer(BUFFER_CAPACITY) for _ in range(2)]
        self.streaming = False
        self.mode = 0
        self.logger: CsvLogger | None = None
        self.cal_store = CalibrationStore()
        self.config: proto.Config | None = None
        # After a calibration is applied, buffered samples older than this
        # were converted with the previous calibration — never reuse them.
        self._cal_markers: list[float | None] = [None, None]
        self._disp_t1: float | None = None  # smoothed right edge for follow mode

        self.plots = LivePlots()
        self.setCentralWidget(self.plots)
        self._build_toolbar()
        self._build_statusbar()
        self._build_region_dock()

        self.region_timer = QTimer(self)
        self.region_timer.setInterval(150)
        self.region_timer.setSingleShot(True)
        self.region_timer.timeout.connect(self._update_region_panel)
        self.plots.region.sigRegionChanged.connect(
            lambda: self.region_timer.start()
        )

        self.plot_timer = QTimer(self)
        self.plot_timer.setInterval(33)  # ~30 Hz
        self.plot_timer.timeout.connect(self._refresh_plots)
        self.plot_timer.start()

        # Bus-voltage plausibility check (floating GND / open VBus jumper).
        self.health_timer = QTimer(self)
        self.health_timer.setInterval(500)
        self.health_timer.timeout.connect(self._check_bus_health)
        self.health_timer.start()

        # Manual pan/zoom on the time axis takes over from follow mode.
        self.plots.plots[0].getViewBox().sigRangeChangedManually.connect(
            lambda *_: self.follow_check.setChecked(False)
        )

    # -- UI scaffolding ----------------------------------------------------

    def _build_toolbar(self) -> None:
        tb = QToolBar("Controls")
        tb.setMovable(False)
        self.addToolBar(tb)

        self.port_combo = QComboBox()
        self.port_combo.setMinimumWidth(220)
        self._refresh_ports()
        tb.addWidget(QLabel(" Port: "))
        tb.addWidget(self.port_combo)

        refresh = QPushButton("⟳")
        refresh.setFixedWidth(28)
        refresh.clicked.connect(self._refresh_ports)
        tb.addWidget(refresh)

        self.connect_btn = QPushButton("Connect")
        self.connect_btn.clicked.connect(self._toggle_connect)
        tb.addWidget(self.connect_btn)

        self.start_btn = QPushButton("Start")
        self.start_btn.setEnabled(False)
        self.start_btn.clicked.connect(self._toggle_stream)
        tb.addWidget(self.start_btn)

        tb.addSeparator()
        tb.addWidget(QLabel(" Mode: "))
        self.mode_combo = QComboBox()
        self.mode_combo.addItems(["single", "dual"])
        self.mode_combo.currentIndexChanged.connect(self._mode_changed)
        tb.addWidget(self.mode_combo)

        tb.addWidget(QLabel(" Preset: "))
        self.preset_combo = QComboBox()
        self.preset_combo.addItems(list(proto.PRESETS))
        self.preset_combo.setCurrentText("fast-dual")
        self.preset_combo.currentTextChanged.connect(self._preset_changed)
        tb.addWidget(self.preset_combo)

        tb.addWidget(QLabel(" Range: "))
        self.range_combo = QComboBox()
        self.range_combo.addItems(["±163.84 mV (8 µA)", "±40.96 mV (2 µA)"])
        self.range_combo.currentIndexChanged.connect(self._preset_changed)
        tb.addWidget(self.range_combo)

        tb.addSeparator()
        tb.addWidget(QLabel(" Window: "))
        self.window_spin = QDoubleSpinBox()
        self.window_spin.setRange(0.1, 2700.0)
        self.window_spin.setValue(10.0)
        self.window_spin.setSuffix(" s")
        tb.addWidget(self.window_spin)

        self.follow_check = QCheckBox("Follow")
        self.follow_check.setChecked(True)
        tb.addWidget(self.follow_check)

        reset_view_btn = QPushButton("Reset view")
        reset_view_btn.clicked.connect(self._reset_view)
        tb.addWidget(reset_view_btn)

        tb.addSeparator()
        self.measure_check = QCheckBox("Measure")
        self.measure_check.toggled.connect(self._toggle_measure)
        tb.addWidget(self.measure_check)

        self.log_btn = QPushButton("Log CSV…")
        self.log_btn.setCheckable(True)
        self.log_btn.toggled.connect(self._toggle_logging)
        tb.addWidget(self.log_btn)

        tb.addSeparator()
        self.cal_btn = QPushButton("Calibrate…")
        self.cal_btn.setEnabled(False)
        self.cal_btn.clicked.connect(self._open_calibration)
        tb.addWidget(self.cal_btn)

        self.adv_btn = QPushButton("Advanced…")
        self.adv_btn.setEnabled(False)
        self.adv_btn.clicked.connect(self._open_advanced)
        tb.addWidget(self.adv_btn)

    def _build_statusbar(self) -> None:
        self.status_conn = QLabel("disconnected")
        self.status_rate = QLabel("")
        self.status_drops = QLabel("")
        self.status_log = QLabel("")
        for w in (self.status_conn, self.status_rate, self.status_drops, self.status_log):
            self.statusBar().addWidget(w)
            w.setMargin(4)
        # Right-aligned, red; only visible while a channel's VBUS looks wrong.
        self.status_warn = QLabel("")
        self.status_warn.setMargin(4)
        self.status_warn.setStyleSheet("color: #c62828; font-weight: bold;")
        self.status_warn.setToolTip(
            "The bus voltage cannot be a real DC supply. Usual causes: the supply "
            "'-' is not connected to the GND terminal (J5), or the VBus jumper on "
            "the INA228 is open. See docs/troubleshooting.md")
        self.statusBar().addPermanentWidget(self.status_warn)

    def _build_region_dock(self) -> None:
        self.region_dock = QDockWidget("Region", self)
        self.region_dock.setFeatures(QDockWidget.DockWidgetFeature.DockWidgetClosable)
        self.region_label = QLabel("enable Measure and drag the region")
        self.region_label.setTextFormat(Qt.TextFormat.RichText)
        self.region_label.setAlignment(Qt.AlignmentFlag.AlignTop)
        self.region_label.setMargin(8)
        self.region_dock.setWidget(self.region_label)
        self.addDockWidget(Qt.DockWidgetArea.RightDockWidgetArea, self.region_dock)
        self.region_dock.hide()

    # -- connection lifecycle ------------------------------------------------

    def _refresh_ports(self) -> None:
        self.port_combo.clear()
        self.port_combo.addItems(find_ports())

    def _toggle_connect(self) -> None:
        if self.worker is not None:
            self.worker.shutdown()
            return
        # Each session restarts device time at 0 — stale samples from the
        # previous session would break the buffers' time monotonicity.
        self.buffers = [ChannelBuffer(BUFFER_CAPACITY) for _ in range(2)]
        self._disp_t1 = None
        self._cal_markers = [None, None]
        port = self.port_combo.currentText() or None
        self.worker = SerialWorker(port, cal_store=self.cal_store)
        self.worker.connected.connect(self._on_connected)
        self.worker.config_updated.connect(self._on_config)
        self.worker.samples.connect(self._on_samples)
        self.worker.stats.connect(self._on_stats)
        self.worker.error.connect(self._on_error)
        self.worker.finished_session.connect(self._on_session_end)
        self.worker.start()
        self.connect_btn.setText("Disconnect")

    def _on_connected(self, hello: proto.HelloAck) -> None:
        fw = ".".join(map(str, hello.fw_version))
        self.status_conn.setText(
            f"fw {fw}  board {hello.board_id}  ch 0x{hello.ch_present:02X}"
        )
        self.start_btn.setEnabled(True)
        self.mode_combo.setEnabled(bool(hello.ch_present & 2))
        self.cal_btn.setEnabled(True)
        self.adv_btn.setEnabled(True)

    def _on_config(self, cfg: proto.Config) -> None:
        self.mode = cfg.mode
        self.config = cfg
        self.status_drops.setText(f"ring drops: {cfg.drops}")

    def _on_session_end(self) -> None:
        if self.worker is not None:
            self.worker.wait(2000)
            self.worker = None
        self.streaming = False
        self.connect_btn.setText("Connect")
        self.start_btn.setText("Start")
        self.start_btn.setEnabled(False)
        self.cal_btn.setEnabled(False)
        self.adv_btn.setEnabled(False)
        self.status_conn.setText("disconnected")
        self.status_warn.setText("")

    def _on_error(self, msg: str) -> None:
        QMessageBox.warning(self, "picowatt", msg)

    # -- device commands -----------------------------------------------------

    def _toggle_stream(self) -> None:
        if self.worker is None:
            return
        if self.streaming:
            self.worker.submit(lambda d: d.stop())
            self.streaming = False
            self.start_btn.setText("Start")
        else:
            self.worker.submit(lambda d: d.start())
            self.streaming = True
            self.start_btn.setText("Stop")

    def _mode_changed(self, idx: int) -> None:
        if self.worker is not None:
            self.worker.submit(lambda d: d.set_mode(idx))

    def _preset_changed(self) -> None:
        if self.worker is None:
            return
        preset = self.preset_combo.currentText()
        adcrange = self.range_combo.currentIndex()
        self.worker.submit(lambda d: d.set_preset(preset, adcrange=adcrange))

    # -- region measurement ----------------------------------------------------

    def _toggle_measure(self, on: bool) -> None:
        self.plots.show_region(on)
        self.region_dock.setVisible(on)
        if on:
            self._update_region_panel()

    @staticmethod
    def _fmt(val: float, unit: str) -> str:
        for factor, prefix in ((1.0, ""), (1e3, "m"), (1e6, "µ")):
            if abs(val) * factor >= 1.0 or prefix == "µ":
                return f"{val * factor:.4f} {prefix}{unit}"
        return f"{val:.4f} {unit}"

    def _update_region_panel(self) -> None:
        if not self.measure_check.isChecked():
            return
        t0, t1 = self.plots.region_bounds()
        nch = 2 if self.mode == 1 else 1
        parts = [f"<b>Δt</b> {t1 - t0:.3f} s"]
        results = {}
        for c in range(nch):
            r = integrate_region(self.buffers[c], t0, t1)
            results[c] = r
            if r is None:
                parts.append(f"<br><b>ch{c}</b>: no data")
                continue
            parts.append(
                f"<br><b>ch{c} ({CH_NAMES[c]})</b>  n={r.n}"
                f"<br>&nbsp;&nbsp;V<sub>avg</sub> {self._fmt(r.avg_v, 'V')}"
                f"<br>&nbsp;&nbsp;I<sub>avg</sub> {self._fmt(r.avg_i, 'A')}"
                f"<br>&nbsp;&nbsp;P<sub>avg</sub> {self._fmt(r.avg_w, 'W')}"
                f"<br>&nbsp;&nbsp;<b>E {self._fmt(r.wh, 'Wh')}</b>"
                f"<br>&nbsp;&nbsp;Q {self._fmt(r.ah, 'Ah')}"
            )
        if nch == 2 and results.get(0) and results.get(1) and results[0].wh > 0:
            eff = 100.0 * results[1].wh / results[0].wh
            parts.append(f"<br><b>η</b> {eff:.2f} %")
        self.region_label.setText("".join(parts))

    # -- calibration / advanced settings ---------------------------------------

    def _mean_current(self, ch: int) -> tuple[float, int]:
        """Mean displayed current over the last second of post-calibration data."""
        buf = self.buffers[ch]
        t_last = buf.latest_t()
        if t_last is None:
            return 0.0, 0
        t_lo = t_last - 1.0
        marker = self._cal_markers[ch]
        if marker is not None:
            # 0.3 s margin covers the config round-trip on the worker thread
            t_lo = max(t_lo, marker + 0.3)
        if t_last - t_lo < 0.4:
            return 0.0, 0  # not enough fresh data yet
        t, _v, i = buf.window(t_lo, t_last)
        if len(i) == 0:
            return 0.0, 0
        return float(np.mean(i.astype(np.float64))), len(t)

    def _mark_calibration(self, ch: int) -> None:
        self._cal_markers[ch] = self.buffers[ch].latest_t()

    def _open_calibration(self) -> None:
        if self.worker is None or self.worker.board_id is None or self.config is None:
            return
        board = self.worker.board_id

        def get_shunt_cal(ch: int) -> int:
            assert self.config is not None
            return self.config.ch[ch].shunt_cal

        def apply_zero(ch: int, delta_a: float) -> None:
            assert self.config is not None and self.worker is not None
            adcrange = self.config.ch[ch].adcrange
            old = self.cal_store.get(board, ch).offset_for(adcrange)
            self.cal_store.set_zero_offset(board, ch, adcrange, old + delta_a)
            # No-op command forces a config round-trip -> worker reloads offsets
            self.worker.submit(lambda d: None)
            self._mark_calibration(ch)

        def apply_gain(ch: int, new_cal: int) -> None:
            assert self.worker is not None
            self.cal_store.set_shunt_cal(board, ch, new_cal)
            self.worker.submit(lambda d: d.set_shunt_cal(ch, new_cal))
            self._mark_calibration(ch)

        def apply_reset(ch: int) -> None:
            assert self.config is not None and self.worker is not None
            from .calibration import DEFAULT_SHUNT_CAL, ChannelCal
            self.cal_store.set(board, ch, ChannelCal())
            self.worker.submit(lambda d: d.set_shunt_cal(ch, DEFAULT_SHUNT_CAL))
            self._mark_calibration(ch)

        CalibrationDialog(
            self, self._mean_current, get_shunt_cal, apply_zero, apply_gain, apply_reset
        ).exec()

    def _open_advanced(self) -> None:
        if self.worker is None or self.config is None:
            return

        def apply_fn(ch: int, adcrange: int, vbusct: int, vshct: int, avg: int) -> None:
            assert self.worker is not None
            self.worker.submit(lambda d: d.set_adc(ch, adcrange, vbusct, vshct, avg))

        AdvancedSettingsDialog(self, self.config, apply_fn).exec()

    # -- CSV logging -----------------------------------------------------------

    def _toggle_logging(self, on: bool) -> None:
        if on:
            path, _ = QFileDialog.getSaveFileName(
                self, "Log to CSV", "picowatt.csv", "CSV files (*.csv)"
            )
            if not path:
                self.log_btn.setChecked(False)
                return
            meta = {"device": self.status_conn.text()}
            if self.worker is not None and self.worker.isRunning():
                meta["mode"] = "dual" if self.mode == 1 else "single"
            self.logger = CsvLogger(path, meta)
            self.log_btn.setText("Stop log")
            self.status_log.setText(f"logging → {path}")
        else:
            if self.logger is not None:
                self.logger.stop()
                self.status_log.setText(
                    f"logged {self.logger.rows_written} rows"
                    + (f" ({self.logger.dropped_batches} batches dropped)"
                       if self.logger.dropped_batches else "")
                )
                self.logger = None
            self.log_btn.setText("Log CSV…")

    # -- data path -----------------------------------------------------------

    def _on_samples(self, ch: int, t: np.ndarray, v: np.ndarray, i: np.ndarray) -> None:
        self.buffers[ch].append(t, v, i)
        if self.logger is not None:
            self.logger.log(ch, t, v, i)

    def _on_stats(self, gaps: int, _drops: int) -> None:
        self.status_rate.setText(f"frame gaps: {gaps}")

    def _check_bus_health(self) -> None:
        """Warn in the status bar when VBUS over the last second is implausible."""
        if not self.streaming:
            return
        nch = 2 if self.mode == 1 else 1
        msgs = []
        for c in range(nch):
            buf = self.buffers[c]
            t_last = buf.latest_t()
            if t_last is None:
                continue
            _t, v, _i = buf.window(t_last - 1.0, t_last)
            if len(v) < 10:
                continue
            h = check_vbus(v)
            if h.problem:
                msgs.append(f"ch{c}: {h.problem}")
        if msgs:
            self.status_warn.setText("\u26a0 " + "   ".join(msgs)
                                     + " \u2014 check GND link to J5 / VBus jumper")
        else:
            self.status_warn.setText("")

    def _reset_view(self) -> None:
        self.plots.reset_view()
        self._disp_t1 = None
        self.follow_check.setChecked(True)

    def _refresh_plots(self) -> None:
        latest = [b.latest_t() for b in self.buffers]
        t_last = max((t for t in latest if t is not None), default=None)
        if t_last is None:
            return
        if self.follow_check.isChecked():
            # Exponential approach to the newest sample: data arrives in USB
            # bursts, and snapping the range to each burst looks jerky.
            if self._disp_t1 is None or t_last < self._disp_t1:
                self._disp_t1 = t_last
            else:
                self._disp_t1 += 0.35 * (t_last - self._disp_t1)
            t1 = self._disp_t1
            t0 = t1 - self.window_spin.value()
        else:
            # Feed whatever time range the user has panned/zoomed to.
            x0, x1 = self.plots.plots[0].viewRange()[0]
            pad = (x1 - x0) * 0.1
            t0, t1 = x0 - pad, x1 + pad
        nch = 2 if self.mode == 1 else 1
        for c in range(2):
            if c < nch and self.buffers[c].count:
                self.plots.update_channel(c, self.buffers[c], t0, t1)
            else:
                self.plots.update_channel(c, ChannelBuffer(1), 0, 0)
        if self.follow_check.isChecked():
            self.plots.set_x_range(t0, t1)

    def closeEvent(self, event) -> None:
        if self.logger is not None:
            self.logger.stop()
        if self.worker is not None:
            self.worker.shutdown()
            self.worker.wait(2000)
        event.accept()


def main() -> int:
    app = QApplication(sys.argv)
    app.setApplicationName("picowatt")
    win = MainWindow()
    win.show()
    return app.exec()


if __name__ == "__main__":
    sys.exit(main())

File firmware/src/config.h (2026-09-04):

#ifndef PICOWATT_CONFIG_H
#define PICOWATT_CONFIG_H

// ---- Firmware version ----
#define FW_VERSION_MAJOR 0
#define FW_VERSION_MINOR 1
#define FW_VERSION_PATCH 1

// ---- I2C bus ----
#define PW_I2C            i2c0
#define PW_I2C_SDA_PIN    4   // GP4, pin 6
#define PW_I2C_SCL_PIN    5   // GP5, pin 7
#define PW_I2C_BAUD_HZ    1000000  // 1 MHz; fall back to 400 kHz if unstable

// ---- Device addresses ----
#define INA228_ADDR_IN    0x40  // channel 0, input side (#1)
#define INA228_ADDR_OUT   0x41  // channel 1, output side (#2, A0 jumper closed)
#define SSD1306_ADDR      0x3C

// ---- Reserved for optional ALERT wiring (not used yet) ----
#define INA228_ALERT_IN_PIN   6   // GP6
#define INA228_ALERT_OUT_PIN  7   // GP7

// ---- Shunt / calibration defaults (see docs/calibration.md) ----
#define PW_SHUNT_OHMS         0.015f
#define PW_SHUNT_CAL_DEFAULT  1573  // ADCRANGE=0: LSB 8 uA; ADCRANGE=1: LSB 2 uA

#endif // PICOWATT_CONFIG_H

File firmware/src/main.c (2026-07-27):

// picowatt firmware — core0: USB CDC binary protocol; core1: sampling (sampler.c).
// Copyright (C) 2026  Ryotaro Okamoto
// SPDX-License-Identifier: GPL-3.0-or-later

#include <string.h>
#include "pico/bootrom.h"
#include "pico/stdlib.h"
#include "tusb.h"
#include "config.h"
#include "commands.h"
#include "proto.h"
#include "ring.h"
#include "sampler.h"

#define RECORDS_PER_FRAME 20
#define RECORD_BYTES 13
#define FLUSH_INTERVAL_US 10000

// Serialized DATA frame payload: frame_seq u16 | count u8 | records
static uint8_t data_payload[3 + RECORDS_PER_FRAME * RECORD_BYTES];
static uint16_t frame_seq = 0;
static uint8_t pending = 0;
static uint32_t last_flush_us = 0;

static void put_record(const sample_t *s) {
    uint8_t *b = data_payload + 3 + (size_t)pending * RECORD_BYTES;
    b[0] = s->ch;
    memcpy(b + 1, &s->t_us, 4);
    memcpy(b + 5, &s->vbus_raw, 4);
    memcpy(b + 9, &s->curr_raw, 4);
    pending++;
}

static void flush_data_frame(void) {
    if (pending == 0) return;
    data_payload[0] = (uint8_t)(frame_seq & 0xFF);
    data_payload[1] = (uint8_t)(frame_seq >> 8);
    data_payload[2] = pending;
    commands_send_frame(FRAME_DATA, data_payload, 3 + (size_t)pending * RECORD_BYTES);
    frame_seq++;
    pending = 0;
    last_flush_us = time_us_32();
}

static void tx_pump(void) {
    // Only pull from the ring when the CDC FIFO can take a full frame,
    // so backpressure stays in the (deep) ring, not in a half-built frame.
    while (tud_cdc_write_available() > 3 * RECORDS_PER_FRAME * RECORD_BYTES / 2 + 16) {
        sample_t s;
        if (!ring_pop(&s)) break;
        put_record(&s);
        if (pending == RECORDS_PER_FRAME) flush_data_frame();
    }
    if (pending > 0 && time_us_32() - last_flush_us > FLUSH_INTERVAL_US) {
        flush_data_frame();
    }
}

static void rx_pump(proto_decoder_t *dec) {
    uint8_t buf[64];
    while (tud_cdc_available()) {
        uint32_t n = tud_cdc_read(buf, sizeof buf);
        for (uint32_t i = 0; i < n; i++) {
            if (proto_decoder_feed(dec, buf[i])) {
                commands_handle(dec->type, dec->payload, dec->payload_len);
            }
        }
    }
}

// Arduino-style touch reset: 1200 baud -> reboot into BOOTSEL for flashing.
void tud_cdc_line_coding_cb(uint8_t itf, const cdc_line_coding_t *coding) {
    (void)itf;
    if (coding->bit_rate == 1200) reset_usb_boot(0, 0);
}

// Host closed the port (DTR dropped): stop streaming so samples don't pile up
// in the ring/CDC FIFO and reappear as a stale backlog on the next session.
void tud_cdc_line_state_cb(uint8_t itf, bool dtr, bool rts) {
    (void)itf;
    (void)rts;
    if (!dtr) g_state.streaming = false;
}

int main(void) {
    gpio_init(PICO_DEFAULT_LED_PIN);
    gpio_set_dir(PICO_DEFAULT_LED_PIN, GPIO_OUT);

    ring_init();
    sampler_start();
    tusb_init();

    proto_decoder_t dec;
    proto_decoder_init(&dec);

    uint32_t last_led_us = 0;
    bool led_on = false;

    while (true) {
        tud_task();
        rx_pump(&dec);
        tx_pump();

        // LED: 1 Hz idle, 5 Hz streaming
        uint32_t period = g_state.streaming ? 100000 : 500000;
        uint32_t now = time_us_32();
        if (now - last_led_us > period) {
            last_led_us = now;
            led_on = !led_on;
            gpio_put(PICO_DEFAULT_LED_PIN, led_on);
        }
    }
}

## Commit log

2026-07-24 M1: toolchain setup, firmware skeleton (blink + CDC echo), app scaffold
    - firmware/: pico-sdk CMake project for Pico 2 (RP2350), builds picowatt.uf2
    - app/: uv-managed Python package (PySide6/pyqtgraph/pyserial/numpy/cobs)
    - picowatt-cli: USB CDC echo round-trip test
    - build.sh: one-shot firmware build (PICO_SDK_PATH / PICO_TOOLCHAIN_PATH overridable)
2026-07-24 M2: INA228 driver + single-channel V/I/P text output
    - ina228.c: ID-checked init, ADC config, SHUNT_CAL, 20-bit sign-extended reads
    - main.c: continuous sampling (540us CT, 16x avg), 10 Hz text over CDC
    - docs/calibration.md: SHUNT_CAL math, zero/gain calibration procedure
    Verified on hardware: 5.00 V / 0.500 A CC load ->
    V=4.9457 V (lead drop explains offset), I=0.49981 A (-0.04%)
2026-07-24 M3: OLED live display (SSD1306)
    - Vendor daschr/pico-ssd1306 (MIT) into firmware/lib/
    - ssd1306_ui: single/dual layouts, auto-ranged units, boot/error messages
    - main: ~3.3 Hz OLED refresh alongside 10 Hz serial text
    Verified on hardware: OLED matches serial output, I2C stable at 1 MHz
    with INA228 + SSD1306 on the same bus.
    [main.c]
2026-07-24 M4: binary streaming protocol + core split + CLI capture
    Firmware:
    - COBS + CRC16-CCITT framing (proto.c), full command set (commands.c)
    - SPSC lock-free ring (4096 samples), core1 sampler owns I2C exclusively
    - Custom TinyUSB CDC (product string 'picowatt', board-id serial),
    1200-baud touch reset + REBOOT_BOOTSEL command for buttonless flashing
    - OLED page-chunked writes interleaved with sampling (<=1.3 ms stalls)
    App:
    - protocol.py codec (numpy record parsing), device.py session API
    - picowatt-cli: presets, mode switch, CSV capture, drop/gap detection
    - 12 protocol unit tests; ruff clean
    CI: firmware build (pico-sdk 2.3.0) + app lint/test.
    Verified on hardware: fast 3193 Hz, dual 2x17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
    [cli.py, device.py, main.c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]
2026-07-24 M5: GUI realtime plots
    - SerialWorker QThread: owns the Device, command queue, batched numpy emits
    - ChannelBuffer: preallocated 9M-sample ring per channel (~45 min at 3.3 kHz)
    - min/max binning decimation (spikes survive; <=4k points per curve)
    - Stacked V/I/P plots (linked X), follow mode, window length, presets,
    mode/range switching, port auto-detect, drop counters in status bar
    - 8 new unit tests (unwrap, ring wrap, window slicing, spike preservation)
    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
2026-07-24 M6: region energy integration + CSV logging
    - measure.py: trapezoidal Wh/Ah/averages over full-resolution buffer
    - LinearRegionItem on the power plot, debounced region panel dock
    (dt, Vavg/Iavg/Pavg, E, Q per channel; efficiency in dual mode)
    - csv_logger.py: writer-thread CSV with metadata header, drop-safe queue
    - numpy>=2.0 (np.trapezoid); 4 new tests
    Verified on hardware: GUI region 2.4747 W avg vs offline CSV
    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
2026-07-24 M7: dual-channel efficiency mode verified; add verification log
    Series null test: eta = 99.84% (uncalibrated). M78AR05-1 at 12 Vin:
    efficiency plateau 91.7% matches datasheet typical within ~1%.
2026-07-24 M8: calibration UI + per-board profiles; UI polish
    Calibration:
    - calibration.py: JSON profiles keyed by board_id (platformdirs);
    shunt_cal pushed on connect, zero offsets applied PC-side per ADC range
    - Guided Calibrate dialog (zero / one-point gain / reset to defaults)
    - Post-calibration marker excludes stale pre-calibration samples from
    the averaging window (repeated presses no longer compound)
    - Advanced dialog: raw CT/AVG/range with live rate preview
    UI polish (user feedback):
    - OLED shows ~300 ms block averages instead of instantaneous samples
    - Session-relative time axis starting at 0 s, no SI k-prefix on seconds
    - Reset view button (re-enables Y autorange + follow)
    - Smoothed fo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
    [calibration.py, dialogs.py, mainwindow.py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]
2026-07-27 firmware: prevent stale sample backlog across sessions
    A GUI session that disconnected without STOP left the firmware streaming
    into a full ring; the next session then received seconds of stale data,
    shown as 'current' values (root cause of confusing readings during
    calibration). Now:
    - DTR drop (host closed port) stops streaming (tud_cdc_line_state_cb)
    - HELLO stops streaming and clears the ring (fresh session)
    - START clears the ring (stream begins with fresh samples only)
    Verified: abrupt-disconnect + reconnect now yields exactly the capture
    window (3.0 s span, 0 gaps, 0 drops); previously 17.6 s of backlog and
    20k ring drops.
    [main.c]
2026-07-27 M8 verified: reset buffers on reconnect; record calibration results
    - Reconnecting starts device time at 0 again; stale samples from the
    previous session broke buffer time monotonicity and scrambled the plot.
    Buffers/markers now reset on each new connection.
    - verification.md: gain cal 1573->1571, +0.04% at 2 A, reconnect restores
    calibration. All milestones M1-M8 complete.
    [mainwindow.py]
2026-07-27 release automation: tag-triggered UF2 + GitHub Release + PyPI publish
    - .github/workflows/release.yml: on v* tags, build firmware UF2 and
    sdist/wheel, attach with SHA256SUMS to a GitHub Release, publish to
    PyPI via Trusted Publishing (environment: pypi)
    - pyproject: project URLs for PyPI page
    - README: release-based install (UF2 download + uvx picowatt)
2026-07-28 hardware: KiCad carrier board for Pico 2 + INA228 x2 + OLED
    Adds hardware/ with a self-contained KiCad 10 project for a 92x70mm
    two-layer carrier board that replaces the breadboard wiring: Pico 2,
    two Adafruit INA228 breakouts and the Akizuki 112031 SSD1306 OLED all
    plug into 2.54mm sockets, plus a 5.08mm screw terminal for the supply
    ground.
    The power path stays off the carrier -- the INA228 header pins
    VBUS/VIN-/VIN+ are left unconnected so the supply wiring keeps going to
    each breakout's own terminal block. ALERT pullups are provided since
    config.h reserves GP6/GP7 and the INA228 has none.
    Routed on two layers: B.Cu carries +3V3, F.Cu the four signals, GND is
    a pour on both. The pullu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
    [picowatt-carrier.kicad_pcb, picowatt-carrier.kicad_sch]
2026-07-28 hardware: silkscreen pin names, and an Akizuki parts list
    The Akizuki 112031 OLED ships in lots with GND/VCC swapped, and its
    mounting holes are symmetric, so a wrong-pinout module still bolts down
    and gets its supply reversed. Print the pin names on the silkscreen so
    that gets caught while soldering:
    - pin names beside every pad of J2/J3 and J4, rotated to fit the
    2.54mm columns; readable before the module is fitted
    - a board-level line below J4 that stays readable afterwards
    Add a parts list to hardware/README.md covering everything except the
    three modules, with Akizuki product codes verified against their
    product pages.
    Two facts came out of that check. The socket housing he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
    [picowatt-carrier.kicad_pcb, picowatt-carrier.kicad_sch]
2026-07-28 hardware: fabrication notes for the board house
    The 12 mounting holes have to stay non-plated, or the standoff screws
    end up connected to the board ground. The drill files already separate
    PTH from NPTH, but state it in writing too: the note goes in the repo
    and gets copied into the gerber zip as README.txt, so it travels with
    the data even if the order form's remarks box is missed.
    Also records outline, layer count, minimum track/spacing/drill/annular
    ring and the hole breakdown, so the numbers a quote form asks for do
    not have to be re-derived from the board each time.
2026-07-28 hardware: commit the project file as KiCad writes it
    The generator wrote a minimal .kicad_pro, so every time the project was
    opened KiCad filled in its defaults and the file showed up as modified.
    Commit the expanded form instead; it stays stable from here.
    Only defaults were added -- every design rule keeps the value the
    generator set (clearance 0.2, track 0.2/0.4, via 0.8/0.4, edge 0.3,
    annular 0.13), and the root sheet uuid still matches the schematic.
2026-08-21 hardware: channel silkscreen, bigger C1 polarity mark, wiring diagrams
    Assembly surfaced two gaps in the silkscreen. Nothing on the board said
    which INA228 socket is which channel -- "ch0 = 0x40" was printed but the
    J2/J3 mapping only existed as hidden Fab text -- and the J2/J3 reference
    designators themselves sat under the modules. Print "ch0 0x40 IN" /
    "ch1 0x41 OUT" vertically beside each socket, move the references below
    the sockets, and map refs to channels in the bottom note. All of it
    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
    [picowatt-carrier.kicad_pcb, picowatt-carrier.kicad_sch]
2026-08-21 hardware: graphical bench wiring diagrams
    The ASCII wiring diagrams answered "what connects to what" but not
    "where is that on the board". Replace them with SVGs drawn from the
    same carrier coordinates as the board itself, so the drawing matches
    what is on the bench: USB left, terminal blocks facing the top edge,
    J2 = ch0 on the left, J3 = ch1 on the right, J5 top right. Wires are
    colour-coded (+ red / - blue), labelled at each screw, and crossings
    are drawn as hops. One diagram per use case; the power-measurement
    one greys out J3 since it stays empty there.
    Generated by tools/wiring_diagrams.py; GitHub renders the SVGs inline
    in hardware/README.md.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
2026-08-21 hardware: wire both grounds straight to J5's two screws
    Both J5 positions sit on the same GND pour, so the power-measurement
    hookup gets simpler: DUT- into one screw, PSU- into the other, no
    mid-wire splice. The return current between the two screws crosses
    ~5mm of two-layer pour -- well under a milliohm -- and the reference
    ends up closer to DUT- than the old PSU--referenced splice. The
    efficiency diagram loses its floating junction too: both minus wires
    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
2026-09-03 cli: flag a floating-GND bus voltage; docs: troubleshooting with figures
    The headless CLI now reports per-channel VBUS/current statistics and a
    WARNING when the bus voltage cannot be a real DC supply. The check lives
    in measure.check_vbus() and is sign-agnostic: a forgotten GND link
    (supply "-" not brought to J5) shows up as 0 V ... -53 V mains hum, which
    averages negative and would slip past a mean-based test.
    New docs/troubleshooting.md maps symptoms to causes, and both READMEs
    gain a "GND link forgotten" figure plus a concept figure of what VBUS is
    referenced against. Figures are generated by tools/wiring_diagrams.py.
    [cli.py, measure.py]
2026-09-03 gui: status-bar warning when VBUS looks like a floating node
    Every 500 ms while streaming, the last second of each active channel
    goes through measure.check_vbus(); a red permanent status-bar label
    names the channel and the symptom (negative / unstable bus) and points
    at the GND link to J5 and the VBus jumper. Cleared when the bus settles
    or the session ends. Same detector as the CLI WARNING.
    [mainwindow.py]
2026-09-04 README: bench wiring figures; bump to 0.1.1
    Show the carrier-board wiring figures for both measurement modes in the
    top-level README next to the ASCII schematics. Version 0.1.1 for the
    floating-GND diagnostics (CLI + GUI) and troubleshooting docs; firmware
    is unchanged apart from the version fields.
2026-09-04 docs: breadboard wiring figures in the top-level README
    Two generated figures for building picowatt without the carrier board:
    Pico 2 (top view, real pin positions), INA228 x1/x2 and the OLED on
    3V3/GND/SDA/SCL rails, plus the bench power path and the GND link to
    the supply "-". Same generator and colour convention as the carrier
    figures.
